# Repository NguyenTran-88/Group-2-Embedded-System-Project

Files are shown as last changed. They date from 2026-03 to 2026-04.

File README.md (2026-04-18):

# 🎧 MP3/Bluetooth Playback Device  
### STM32-based Audio Player with OLED UI and Analog Audio Switching  

> Embedded Systems Course Project – Group 2  

---

##  Overview

This project implements a **dual-mode audio playback system** based on the **STM32F411CEU6 (Blackpill)** microcontroller.  
The system supports both:

- 🎵 **MP3 playback from SD card** (via DFPlayer Mini)  
- 📶 **Bluetooth audio streaming** (via MH-M28 module)

A compact **OLED interface** provides real-time feedback, while a set of tactile buttons allows intuitive user interaction.

The system integrates both digital control and analog audio switching to create a complete embedded audio device.

---

##  Key Features

- Dual audio source:
  - MP3 playback (DFPlayer Mini)
  - Bluetooth streaming (MH-M28)
- Analog audio source switching using **74HC4053**
- OLED UI (SSD1306) with low-latency updates
- Full playback control:
  - Play / Pause
  - Next / Previous track
  - Volume up / down
  - Mode switching (MP3 ↔ Bluetooth)
- STM32 firmware using HAL (STM32CubeIDE)
- Clean modular firmware architecture
- Real-time UI update with minimal redraw region

---

##  System Highlights

- **Hybrid digital + analog design**  
  Combines MCU control logic with analog audio routing

- **Efficient UI rendering**  
  Partial OLED updates reduce flicker and improve responsiveness

- **Robust multi-source audio handling**  
  Seamless switching between Bluetooth and local playback

- **Full embedded integration**  
  Power management, signal routing, user interface, and firmware tightly coupled

---

##  System Architecture

System Block Diagram

### Main Components

| Component | Description |
|---|---|
| STM32F411CEU6 | Main controller (Blackpill) |
| DFPlayer Mini | MP3 decoder (SD card playback) |
| MH-M28 | Bluetooth audio module |
| LM386 | Audio amplifier |
| 74HC4053BE | Analog multiplexer (audio switching) |
| SSD1306 OLED | Display (I2C) |
| Buck Converter | 12V → 5V power conversion |

---

##  Hardware Interface

- **UART1** → DFPlayer communication  
- **I2C1** → OLED display  
- **GPIO** → Button inputs  
- **GPIO** → Audio mode switching / Bluetooth control  

---

##  Power Architecture

- Input: **12V DC** (adapter or 3x 18650 battery pack)
- Step-down via **buck converter → 5V**
- 5V rail powers:
  - DFPlayer
  - MH-M28
  - LM386
- STM32 uses onboard regulation to **3.3V**

---

## Firmware Structure

```text
firmware/
├── Core/
│   ├── Inc/
│   ├── Src/
│   └── Startup/
├── Drivers/
│   ├── CMSIS/
│   └── STM32F4xx_HAL_Driver/
├── Third_Parties/
    ├── dfplayer/
    └── ssd1306/
```

##  Main Modules

| Module | Responsibility |
|---|---|
| `main.c` | System initialization & entry point |
| `player_service.c` | Playback logic and control |
| `input.c` | Button handling |
| `ui.c` | OLED rendering logic |
| `ui_assets.c` | Bitmap / UI resources |
| `dfplayer` | MP3 control driver |
| `ssd1306` | OLED driver |

---

##  Build & Flash Instructions

### Requirements
- STM32CubeIDE (latest version)
- ST-LINK programmer
- Blackpill STM32F411CEU6 board

---

### Build

1. Open **STM32CubeIDE**
2. Import project:
3. Select the `firmware` folder
4. Build project

### Flash

1. Connect **ST-LINK** to the board  
2. Click **Run / Debug**  
3. Select correct target (**STM32F411CEU6**)  
4. Flash firmware  

---

##  Usage

### Startup Behavior
- System initializes
- OLED displays:
- Current track: `1 / N`
- Initial state: **Paused**

---

### Button Mapping

| Pin | Function |
|-----|---|
| PA3 | Play / Pause |
| PA4 | Previous track |
| PA5 | Next track |
| PA8 | Volume Down |
| PA9 | Volume Up |
| PA10 | Mode Switch (MP3 ↔ Bluetooth) |

---

## Demo & Images

### System Overview
System Overview

### Hardware Prototype
Hardware

### OLED Interface
OLED UI

---

## ✅ Validation & Performance

- ✅ MP3 playback (stable)
- ✅ Bluetooth audio streaming (stable)
- ✅ Audio switching between sources (working correctly)
- ✅ OLED update latency: negligible
- ✅ Full button control verified

### Audio Quality
- Overall: **~8/10**
- Minor noise:
- Slight background noise when idle
- Slightly higher during playback
- Does not affect user experience significantly

---

##  Known Limitations

- Minor analog noise (likely from power/audio coupling)
- No advanced audio filtering yet
- No track metadata display (only index-based)

---

##  Future Improvements

- Improve audio filtering (reduce noise)
- Add track metadata display
- Enhance UI (progress bar, icons)
- Add battery monitoring
- PCB optimization (grounding & analog layout)

---

##  Contributors

- Group 2 – Embedded Systems Project

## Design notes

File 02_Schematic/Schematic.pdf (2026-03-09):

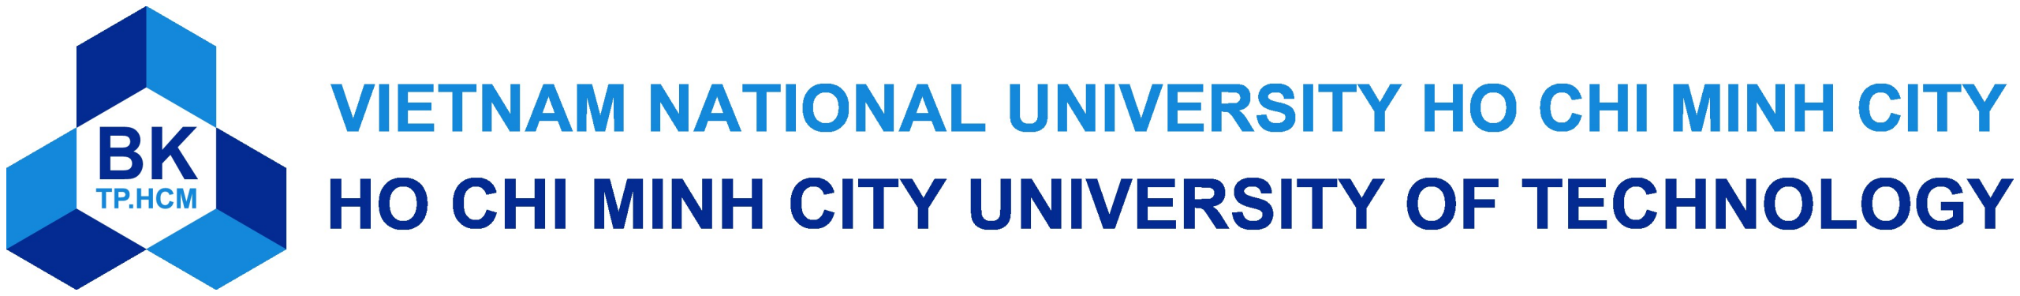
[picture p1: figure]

1

2

3

4

5

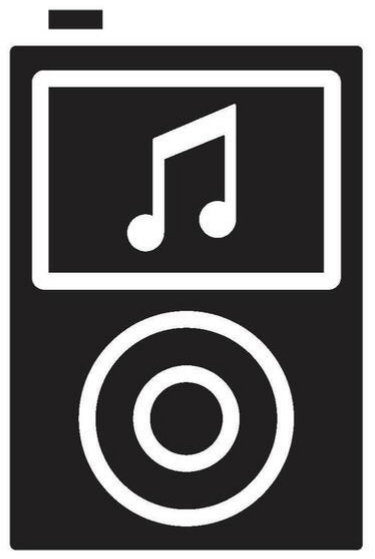
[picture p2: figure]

6

7

8

D D

C C

B B

A A

# PORTABLE AUDIO PLAYER

Title: Main system | Course: Embedded System Design
Designed by: Group 2 | Instructed by: MSc. Bui Quoc Bao
| Sheet 1 of 1 | Size: A3
| Version: 1.0.0 | Date: 13/2/2026

# PORTABLE AUDIO PLAYER

09/03/2026

Page | Content
1.
2.
3.
4. | Cover page System architecture Power tree Schematic

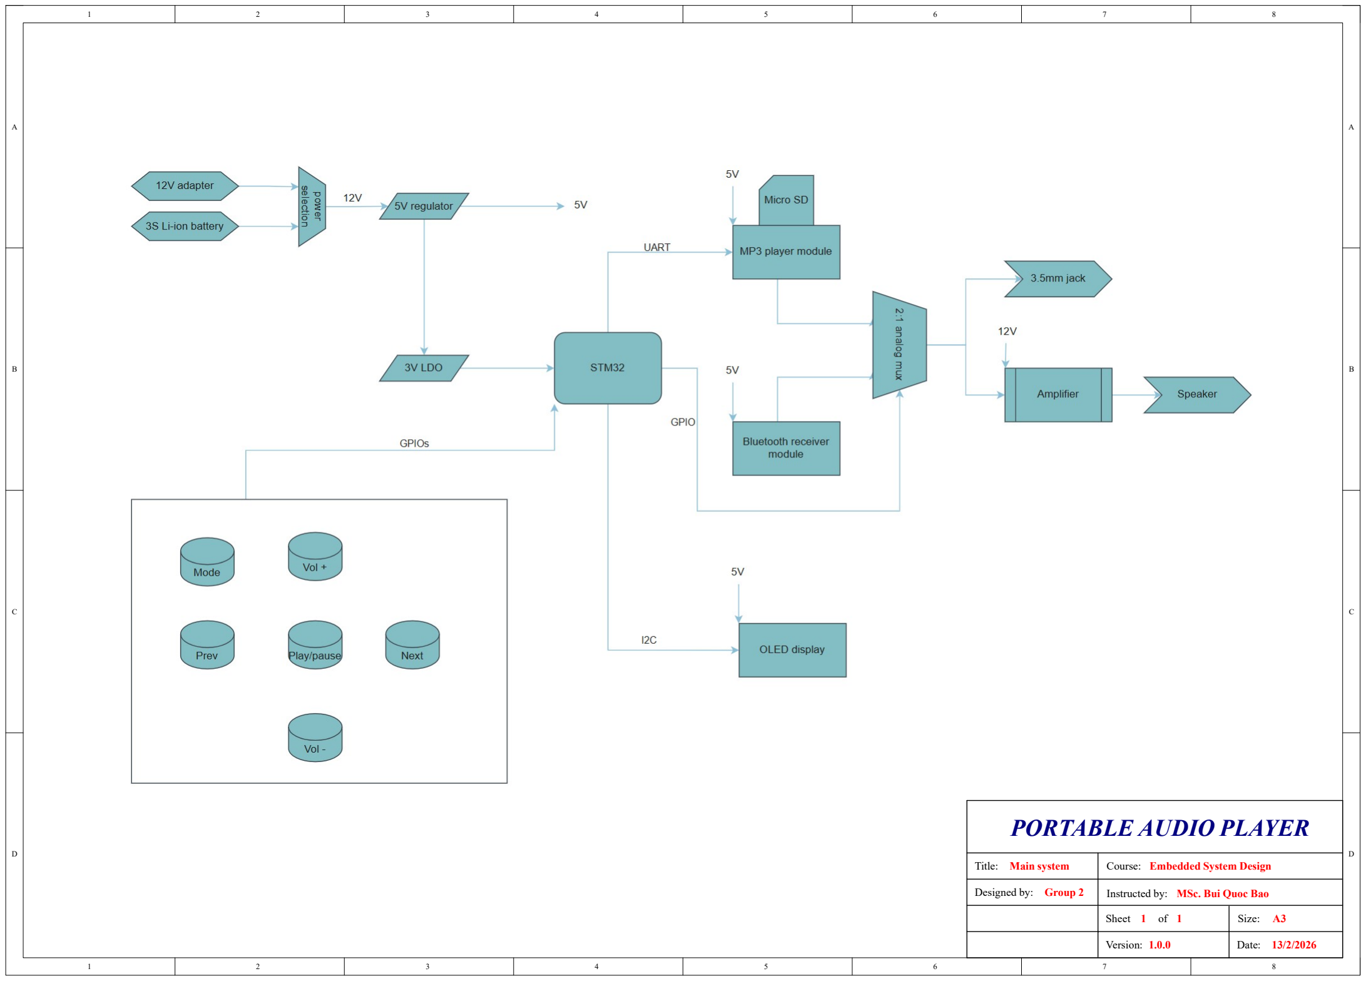
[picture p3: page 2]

D D

C C

B B

A A

# PORTABLE AUDIO PLAYER

Title: Main system | Course: Embedded System Design
Designed by: Group 2 | Instructed by: MSc. Bui Quoc Bao

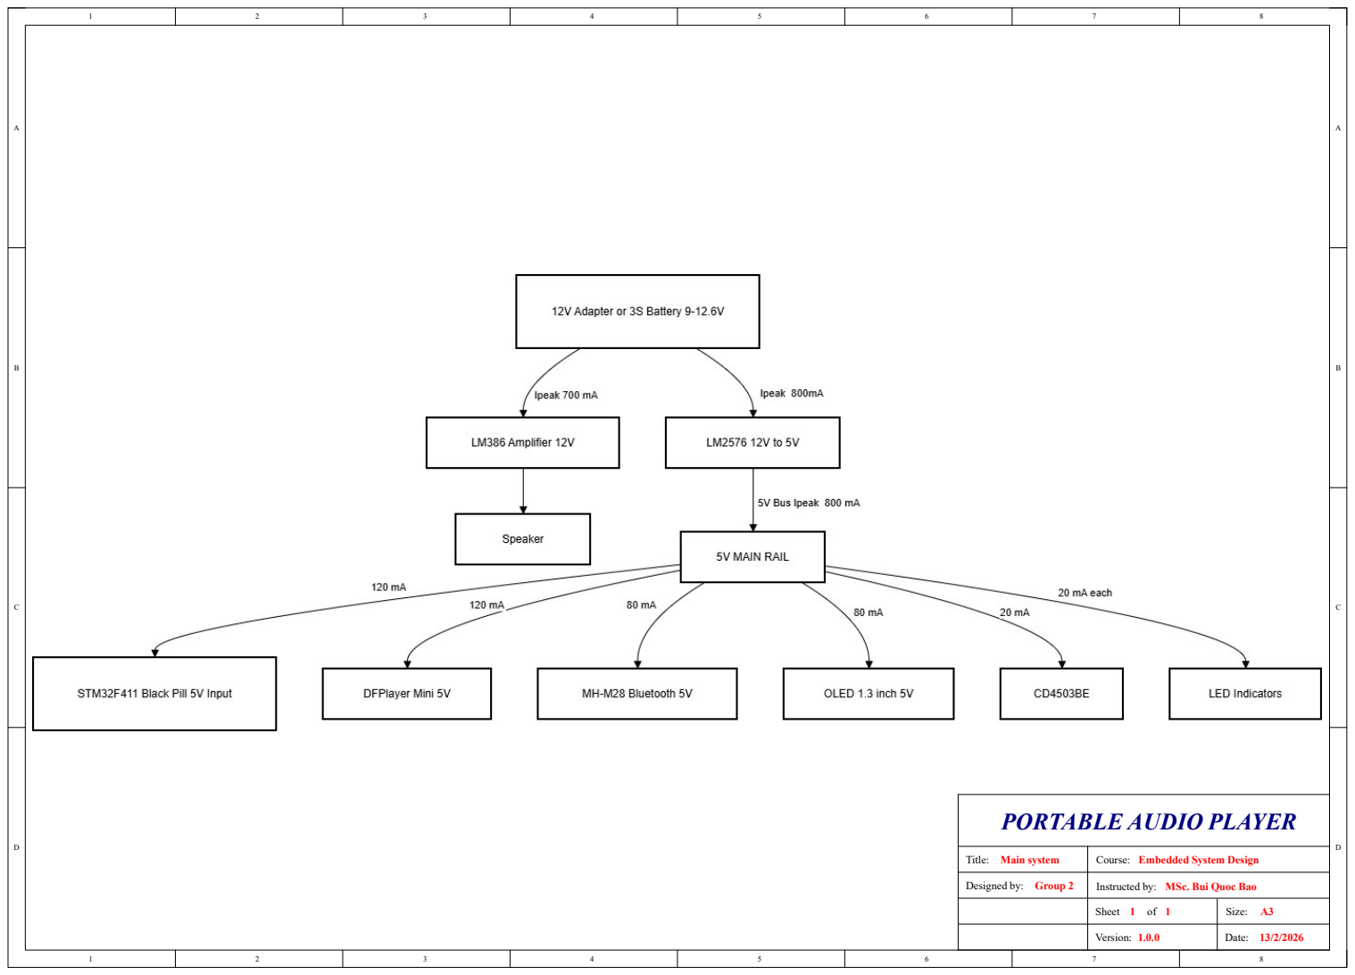
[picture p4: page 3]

D D

C C

B B

A A

# PORTABLE AUDIO PLAYER

Title: Main system | Course: Embedded System Design
Designed by: Group 2 | Instructed by: MSc. Bui Quoc Bao

Power supply | DC converters | Programming interfaces

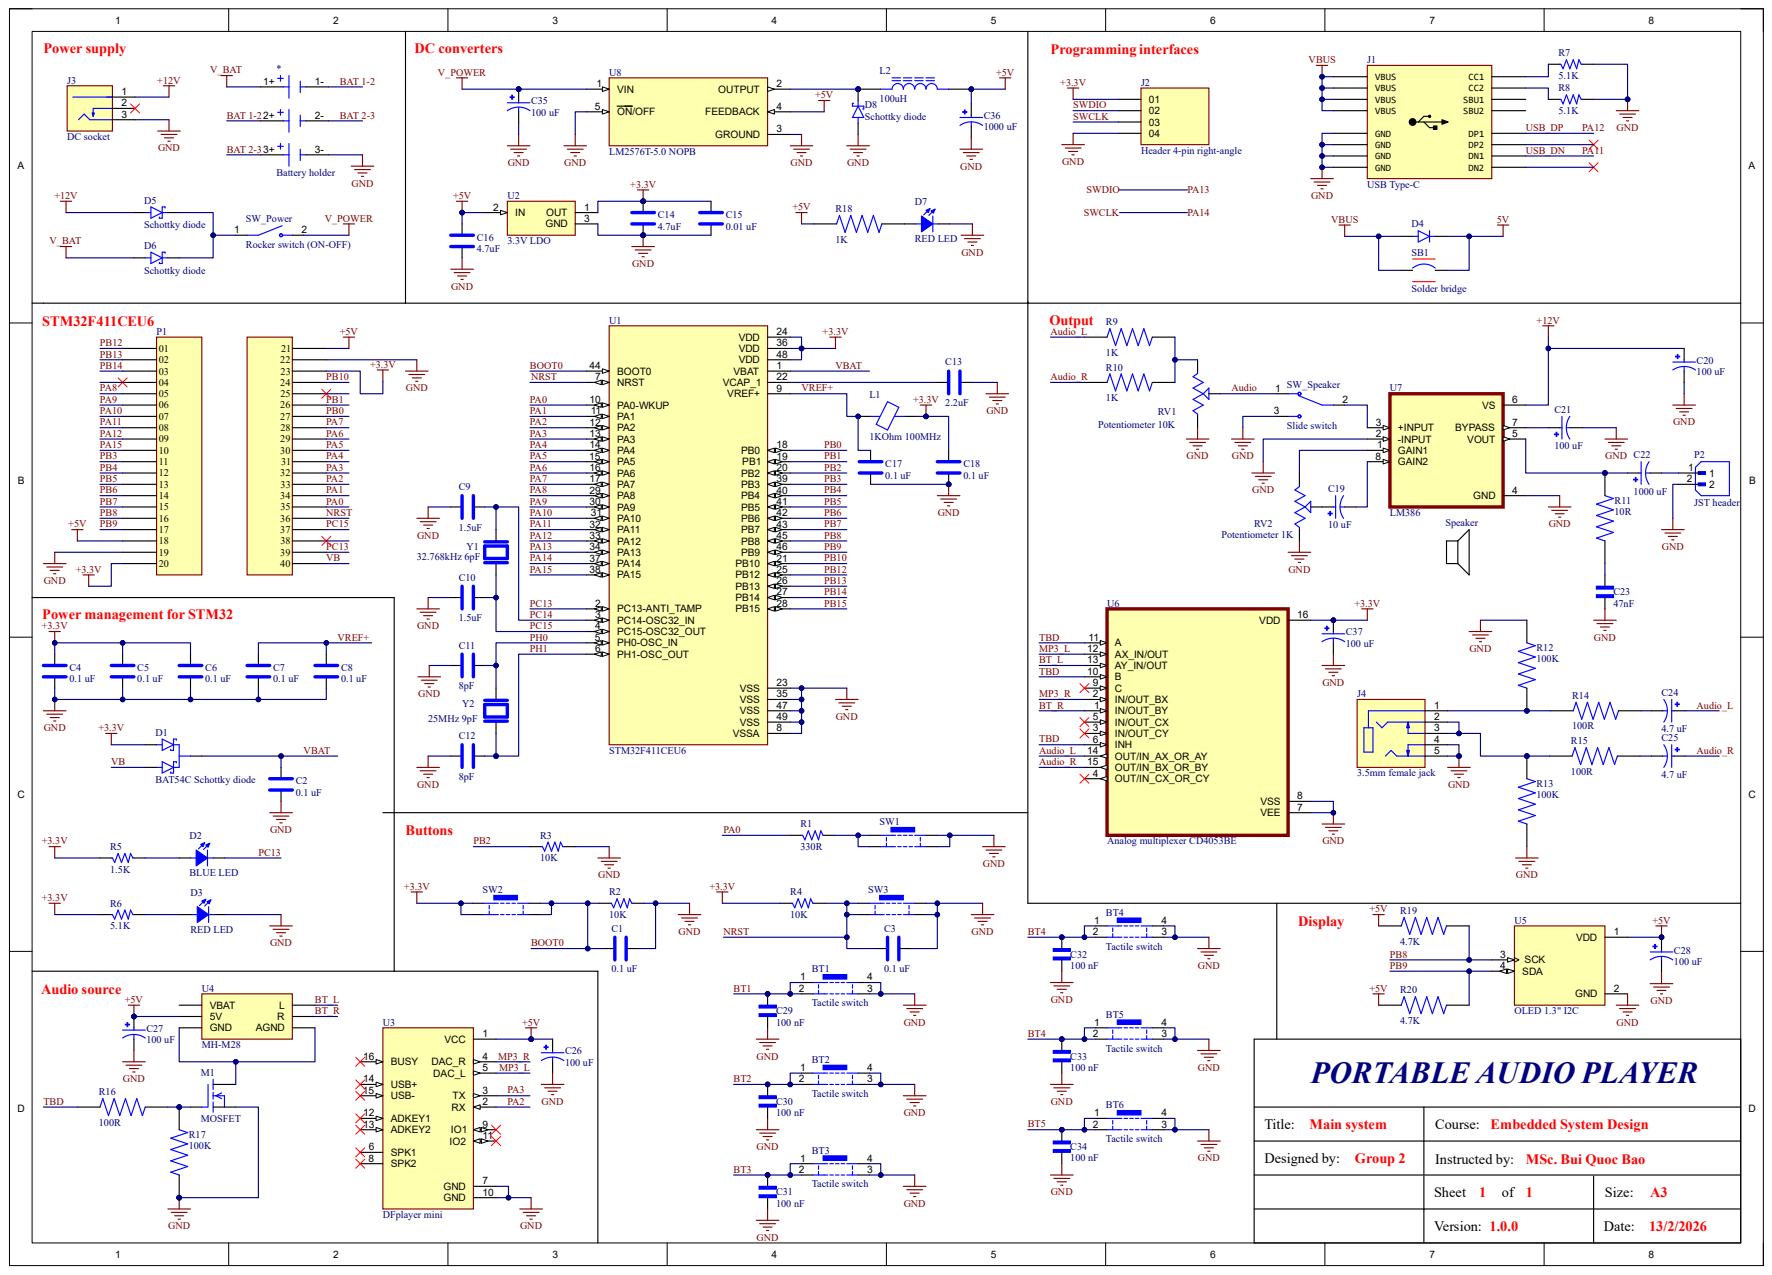
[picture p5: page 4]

Title: Main system | Course: Embedded System Design

Designed by: Group 2 | Instructed by: MSc. Bui Quoc Bao

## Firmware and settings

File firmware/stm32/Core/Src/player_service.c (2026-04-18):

/*
 * player_service.c
 *
 * Playback control service for the STM32 audio player.
 *
 * This module sits between the UI/input layer and the low-level DFPlayer and
 * GPIO control paths. It exists to keep policy decisions in one place:
 * which source is active, when Bluetooth power should be enabled, when the
 * audio path should be muted to avoid switching artifacts, and how the system
 * should interpret playback state for the UI.
 */

#include "player_service.h"
#include <stdint.h>

/*
 * Local operating limits.
 *
 * These values are intentionally kept in the service layer instead of being
 * scattered across UI code, because playback policy belongs here rather than
 * in button handlers.
 */

#define DFPLAYER_VOL_MIN               0u
#define DFPLAYER_VOL_MAX               30u
#define DFPLAYER_VOL_INIT              10u

/*
 * Hardware audio source selection.
 *
 * The service can optionally drive an external analog switch / mux. Keeping
 * the feature under compile-time control makes the module easier to reuse if
 * the hardware changes later.
 */

#define AUDIO_SOURCE_HW_SWITCH_EN      1u

#define AUDIO_SEL_GPIO_Port            GPIOB
#define AUDIO_SEL_Pin                  GPIO_PIN_3

#define AUDIO_INH_GPIO_Port            GPIOB
#define AUDIO_INH_Pin                  GPIO_PIN_4

#define AUDIO_SEL_SD_LEVEL             GPIO_PIN_RESET
#define AUDIO_SEL_BT_LEVEL             GPIO_PIN_SET

#define AUDIO_INH_ENABLE_LEVEL         GPIO_PIN_RESET
#define AUDIO_INH_DISABLE_LEVEL        GPIO_PIN_SET

/*
 * Bluetooth power gating.
 *
 * The Bluetooth module is powered only when needed so the system avoids idle
 * noise injection and unnecessary current draw while operating in SD mode.
 */

#define BT_EN_CONTROL_EN               1u
#define BT_EN_GPIO_Port                GPIOB
#define BT_EN_Pin                      GPIO_PIN_1
#define BT_EN_ACTIVE_LEVEL             GPIO_PIN_SET
#define BT_EN_INACTIVE_LEVEL           GPIO_PIN_RESET

#define BT_BOOT_WAIT_MS                300u

/*
 * DFPlayer BUSY input handling.
 */

#define DFP_BUSY_GPIO_Port             GPIOB
#define DFP_BUSY_Pin                   GPIO_PIN_5

#define DFP_BUSY_ACTIVE_LOW            1u
#define DFP_BUSY_STABLE_MS             20u
#define DFP_BUSY_IGNORE_AFTER_CMD_MS   500u

/*
 * Startup and query timings.
 */

#define DFP_BOOT_INIT_WAIT_MS         2000u
#define DFP_SELECT_TF_WAIT_MS          300u
#define DFP_QUERY_TIMEOUT_MS           300u
#define DFP_NEXT_SETTLE_MS             250u
#define DFP_FALLBACK_MAX_TRACKS        255u

/*
 * Private service state.
 *
 * This block represents the application's working view of playback. The UI is
 * expected to read from this cached state instead of constantly probing the
 * hardware, which keeps rendering logic simpler and avoids unnecessary traffic
 * to the DFPlayer.
 */

static DFPLAYER_Name  g_dfp;

static uint8_t        g_is_playing      = 0u;
static uint8_t        g_df_started_once = 0u;
static uint8_t        g_volume          = DFPLAYER_VOL_INIT;
static AudioSource_t  g_source          = AUDIO_SRC_DFPLAYER_SD;

static uint8_t        g_busy_idle_stable = 1u;
static uint8_t        g_busy_idle_sample = 1u;
static uint32_t       g_busy_tick        = 0u;

static uint32_t       g_dfp_cmd_tick     = 0u;

/*
 * Track count starts with a safe default and is refined during initialization.
 * A non-zero value avoids edge cases in wrap logic if counting fails.
 */

static uint8_t        g_track            = 1u;
static uint8_t        g_track_total      = 5u;


/* Private helpers. */
static void    PlayerService_SetAudioSource(AudioSource_t src);
static uint8_t PlayerService_DfpBusyIdleRaw(void);
static void    PlayerService_AutoNextByBusyService(void);
static void    PlayerService_AudioSwitchMute(uint8_t mute);
static uint8_t PlayerService_DetectTrackTotalByWrap(uint8_t *count_out);
static void    PlayerService_SetBtPower(uint8_t on);


void PlayerService_Init(UART_HandleTypeDef *huart)
{
    DFPLAYER_Init(&g_dfp, huart);

#if BT_EN_CONTROL_EN
    /*
     * Boot in SD mode with Bluetooth powered down.
     *
     * This keeps startup behavior deterministic and avoids bringing up an audio
     * source that is not yet selected.
     */
    PlayerService_SetBtPower(0u);
#endif

#if AUDIO_SOURCE_HW_SWITCH_EN
    /*
    * Mute before touching the source path so initialization side effects do
    * not leak to the speaker, especially during track counting.
    */
    PlayerService_AudioSwitchMute(1u);
    HAL_GPIO_WritePin(AUDIO_SEL_GPIO_Port, AUDIO_SEL_Pin, AUDIO_SEL_SD_LEVEL);
#endif

    /*
     * Give the DFPlayer enough time to finish its own internal power-up and
     * media scan before sending configuration commands.
     */
    HAL_Delay(DFP_BOOT_INIT_WAIT_MS);

    DFPLAYER_SetVolume(&g_dfp, g_volume);

    /*
     * Determine track count by observing wrap-around behavior.
     *
     * The module does not always provide a reliable total-track query in a way
     * that fits this design, so the service derives it using a controlled walk
     * through the playlist.
     */

    if (PlayerService_DetectTrackTotalByWrap(&g_track_total) == 0u)
    {
        g_track_total = 1u;
    }

    g_track = 1u;
    g_is_playing = 0u;
    g_df_started_once = 0u;

#if AUDIO_SOURCE_HW_SWITCH_EN
    HAL_Delay(1);
    PlayerService_AudioSwitchMute(0u);
#endif

    PlayerService_SetAudioSource(AUDIO_SRC_DFPLAYER_SD);

    g_busy_idle_sample = PlayerService_DfpBusyIdleRaw();
    g_busy_idle_stable = g_busy_idle_sample;
    g_busy_tick        = HAL_GetTick();
    g_dfp_cmd_tick     = HAL_GetTick();
}

void PlayerService_Service(void)
{
    PlayerService_AutoNextByBusyService();
}

void PlayerService_PlayToggle(void)
{
    if (g_source != AUDIO_SRC_DFPLAYER_SD)
    {
        return;
    }

    if (g_is_playing == 0u)
    {
        /*
         * Preserve the established project behavior: the first transition into
         * playback uses the standard play command rather than trying to infer a
         * resume point through other means.
         */
        DFPLAYER_Play(&g_dfp);
        g_df_started_once = 1u;
        g_dfp_cmd_tick = HAL_GetTick();
        g_is_playing = 1u;
    }
    else
    {
        DFPLAYER_Pause(&g_dfp);
        g_dfp_cmd_tick = HAL_GetTick();
        g_is_playing = 0u;
    }
}

void PlayerService_Prev(void)
{
    if (g_source != AUDIO_SRC_DFPLAYER_SD)
    {
        return;
    }

    if (g_track_total == 0u)
    {
        g_track_total = 1u;
    }

    g_track = (g_track > 1u) ? (g_track - 1u) : g_track_total;

    if (g_is_playing == 0u)
    {
        g_is_playing = 1u;
        g_df_started_once = 1u;
    }

    DFPLAYER_Prev(&g_dfp);
    g_dfp_cmd_tick = HAL_GetTick();
}
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

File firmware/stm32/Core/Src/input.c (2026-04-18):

/*
 * input.c
 *
 * Button input handling for EXTI-based user controls.
 *
 * Responsibilities:
 * - map GPIO interrupts to application events
 * - debounce button presses in the EXTI callback
 * - push events into a lightweight ISR-safe queue
 */

#include "input.h"
#include <stdint.h>

/*
 * Minimum time between two accepted interrupts from the same button.
 */

#define DEBOUNCE_MS    120u

typedef struct
{
    GPIO_TypeDef *port;
    uint16_t      pin;
    AppEvent_t    evt;
    uint32_t      last_irq_tick;
} ButtonMap_t;

/*
 * Simple ring buffer used to pass button events from ISR context
 * to the main application loop.
 */

static volatile uint8_t  g_evt_q[16];
static volatile uint8_t  g_evt_q_head = 0u;
static volatile uint8_t  g_evt_q_tail = 0u;

/*
 * Debug helpers for checking which EXTI line fired and how often.
 */

static volatile uint16_t g_dbg_last_exti_pin = 0u;
static volatile uint32_t g_dbg_exti_count[16] = {0u};

/*
 * GPIO-to-event mapping for all user buttons.
 */

static ButtonMap_t g_buttons[] =
{
    { GPIOA, GPIO_PIN_3, EVT_PLAY_TOGGLE, 0u }, 	/* PA3 : Play/Pause */
    { GPIOA, GPIO_PIN_4, EVT_PREV_TRACK,  0u }, 	/* PA4 : Previous Track */
    { GPIOA, GPIO_PIN_5, EVT_NEXT_TRACK,  0u }, 	/* PA5 : Next Track */
    { GPIOA, GPIO_PIN_8, EVT_VOL_DOWN,    0u }, 	/* PA8 : Volume Down */
    { GPIOA, GPIO_PIN_9, EVT_VOL_UP,      0u }, 	/* PA9 : Volume Up */
    { GPIOA, GPIO_PIN_10, EVT_MODE_TOGGLE, 0u }, 	/* PA10 : Mode */
};

/* Internal helpers. */

static int32_t Input_FindButtonIndexByPin(uint16_t pin);
static void    Input_PostEventFromISR(AppEvent_t evt);

void Input_Init(void)
{
    uint32_t i;

    __disable_irq();

    g_evt_q_head = 0u;
    g_evt_q_tail = 0u;
    g_dbg_last_exti_pin = 0u;

    for (i = 0u; i < (uint32_t)(sizeof(g_evt_q) / sizeof(g_evt_q[0])); i++)
    {
        g_evt_q[i] = 0u;
    }

    for (i = 0u; i < 16u; i++)
    {
        g_dbg_exti_count[i] = 0u;
    }

    for (i = 0u; i < (uint32_t)(sizeof(g_buttons) / sizeof(g_buttons[0])); i++)
    {
        g_buttons[i].last_irq_tick = 0u;
    }

    __enable_irq();
}

uint8_t Input_PopEvent(AppEvent_t *evt_out)
{
    uint8_t has_data = 0u;

    if (evt_out == NULL)
    {
        return 0u;
    }

    __disable_irq();
    if (g_evt_q_tail != g_evt_q_head)
    {
        *evt_out = (AppEvent_t)g_evt_q[g_evt_q_tail];
        g_evt_q_tail = (uint8_t)((g_evt_q_tail + 1u) % (uint8_t)sizeof(g_evt_q));
        has_data = 1u;
    }
    __enable_irq();

    return has_data;
}

/*
 * EXTI callback from HAL.
 *
 * With the current CubeMX setup (GPIO_MODE_IT_FALLING + pull-up),
 * a falling edge is treated as a valid button press.
 */

void HAL_GPIO_EXTI_Callback(uint16_t GPIO_Pin)
{
    int32_t  idx;
    uint32_t now = HAL_GetTick();

    g_dbg_last_exti_pin = GPIO_Pin;

    idx = Input_FindButtonIndexByPin(GPIO_Pin);
    if (idx < 0)
    {
        return;
    }

    /* Update per-pin debug counters for quick EXTI diagnostics. */
    switch (GPIO_Pin)
    {
        case GPIO_PIN_3:  g_dbg_exti_count[3]++;  break;
        case GPIO_PIN_4:  g_dbg_exti_count[4]++;  break;
        case GPIO_PIN_5:  g_dbg_exti_count[5]++;  break;
        case GPIO_PIN_8:  g_dbg_exti_count[8]++;  break;
        case GPIO_PIN_9:  g_dbg_exti_count[9]++;  break;
        case GPIO_PIN_10:  g_dbg_exti_count[10]++;  break;
        default: break;
    }

    /* Ignore repeated interrupts that arrive within the debounce window. */
    if ((now - g_buttons[(uint32_t)idx].last_irq_tick) < DEBOUNCE_MS)
    {
        return;
    }

    g_buttons[(uint32_t)idx].last_irq_tick = now;

    Input_PostEventFromISR(g_buttons[(uint32_t)idx].evt);
}

static int32_t Input_FindButtonIndexByPin(uint16_t pin)
{
    uint32_t i;

    for (i = 0u; i < (uint32_t)(sizeof(g_buttons) / sizeof(g_buttons[0])); i++)
    {
        if (g_buttons[i].pin == pin)
        {
            return (int32_t)i;
        }
    }

    return -1;
}

static void Input_PostEventFromISR(AppEvent_t evt)
{
    uint8_t next = (uint8_t)((g_evt_q_head + 1u) % (uint8_t)sizeof(g_evt_q));

    /*
    * If the queue is full, the new event is dropped intentionally.
    * This keeps the ISR short and avoids blocking behavior.
    */
    if (next != g_evt_q_tail)
    {
        g_evt_q[g_evt_q_head] = (uint8_t)evt;
        g_evt_q_head = next;
    }

}

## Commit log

2026-03-09 Enhance README with project details and media
    Added project overview, prototype image, and video link.
2026-03-09 Fix image links in README.md
    Updated image links in README for hardware prototype and demo video.
2026-04-18 Add STM32 firmware folder
    [api_1.cfg]
